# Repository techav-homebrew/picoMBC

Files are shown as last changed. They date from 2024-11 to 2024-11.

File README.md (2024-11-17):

# picoMBC

picoMBC is a generic Pi Pico expansion card for the Sanyo MBC-1000 computer. The primary goal is to add an SD card interface for mass storage, but with some available I/O for future or alternate use.

The MBC-1000 expansion interface is a buffered breakout of the Z80 I/O interface. It does not provide the upper 8 bits of the Z80 address bus or signals required for memory space addressing or DMA. To save I/O, picoMBC multiplexes the 8-bit data and address busses.

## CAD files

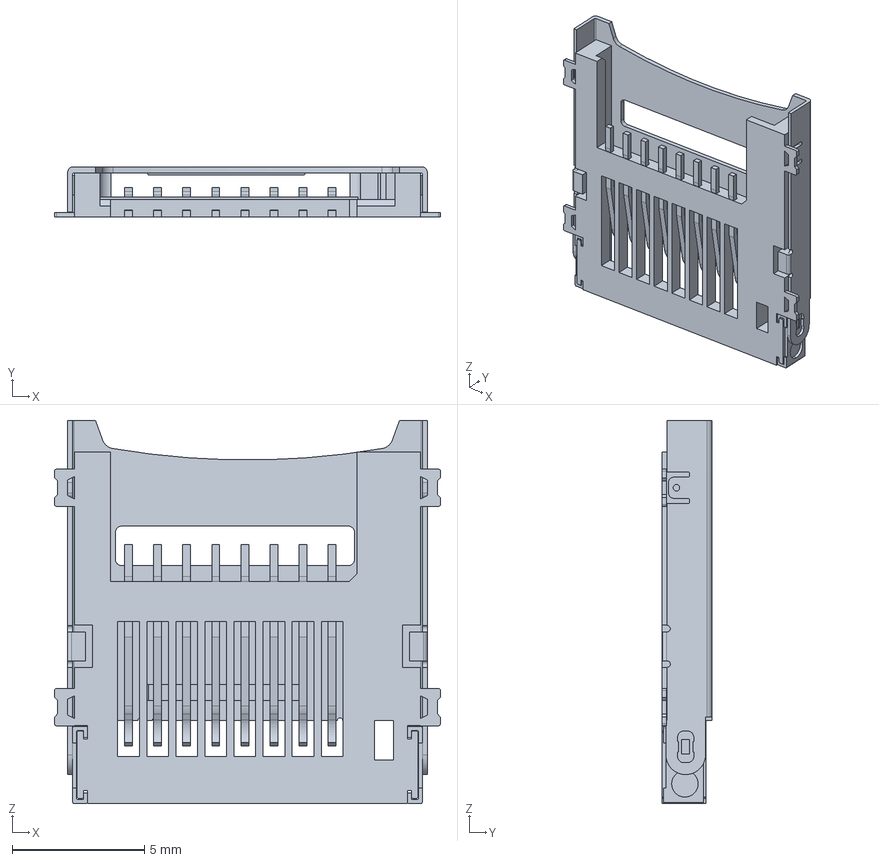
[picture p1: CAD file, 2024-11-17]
hardware/472192001.stp
14.6 x 1.90 x 14.5 mm

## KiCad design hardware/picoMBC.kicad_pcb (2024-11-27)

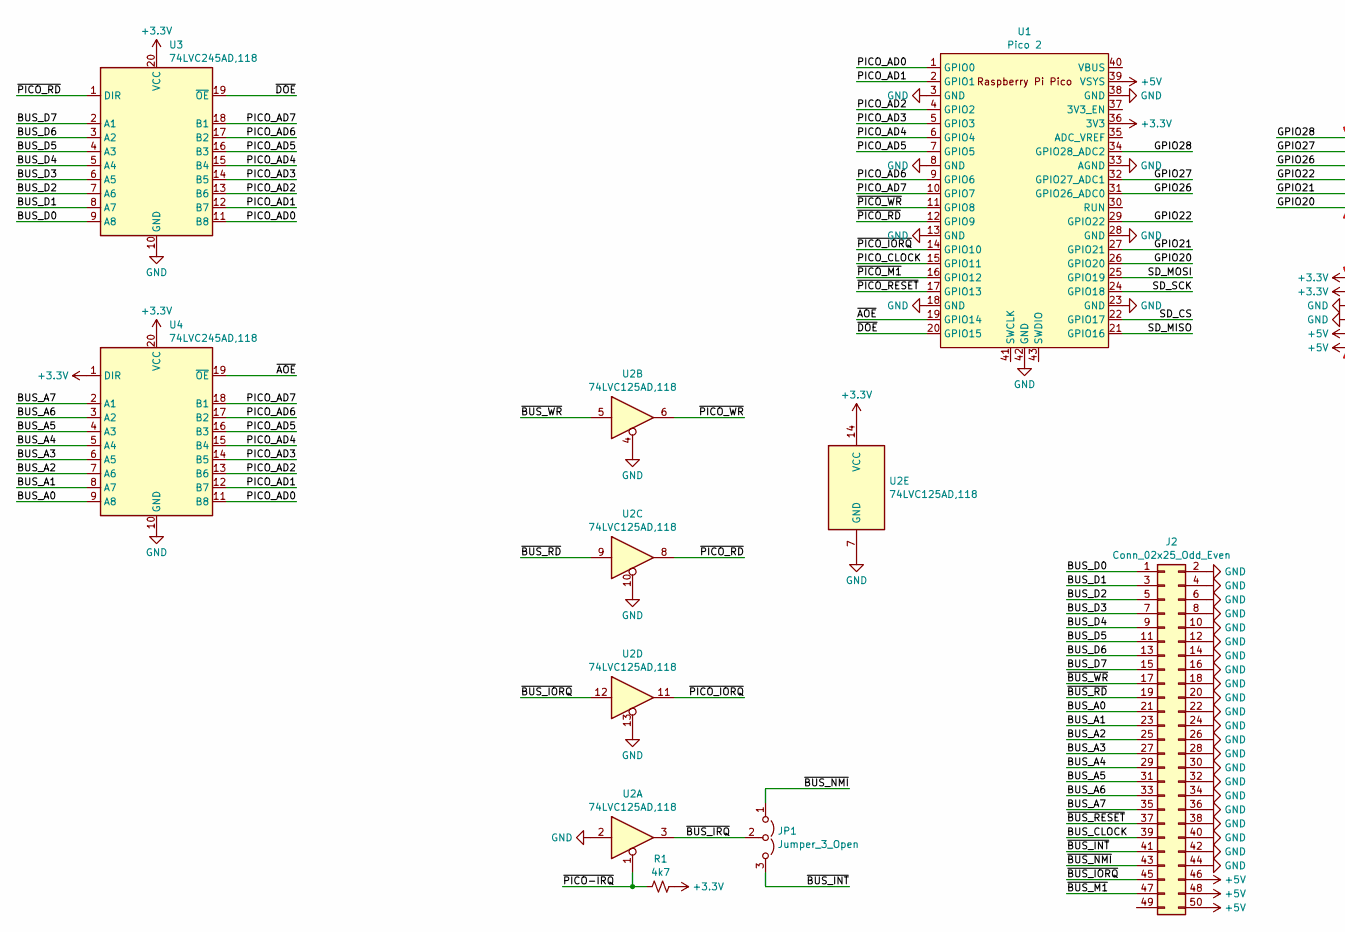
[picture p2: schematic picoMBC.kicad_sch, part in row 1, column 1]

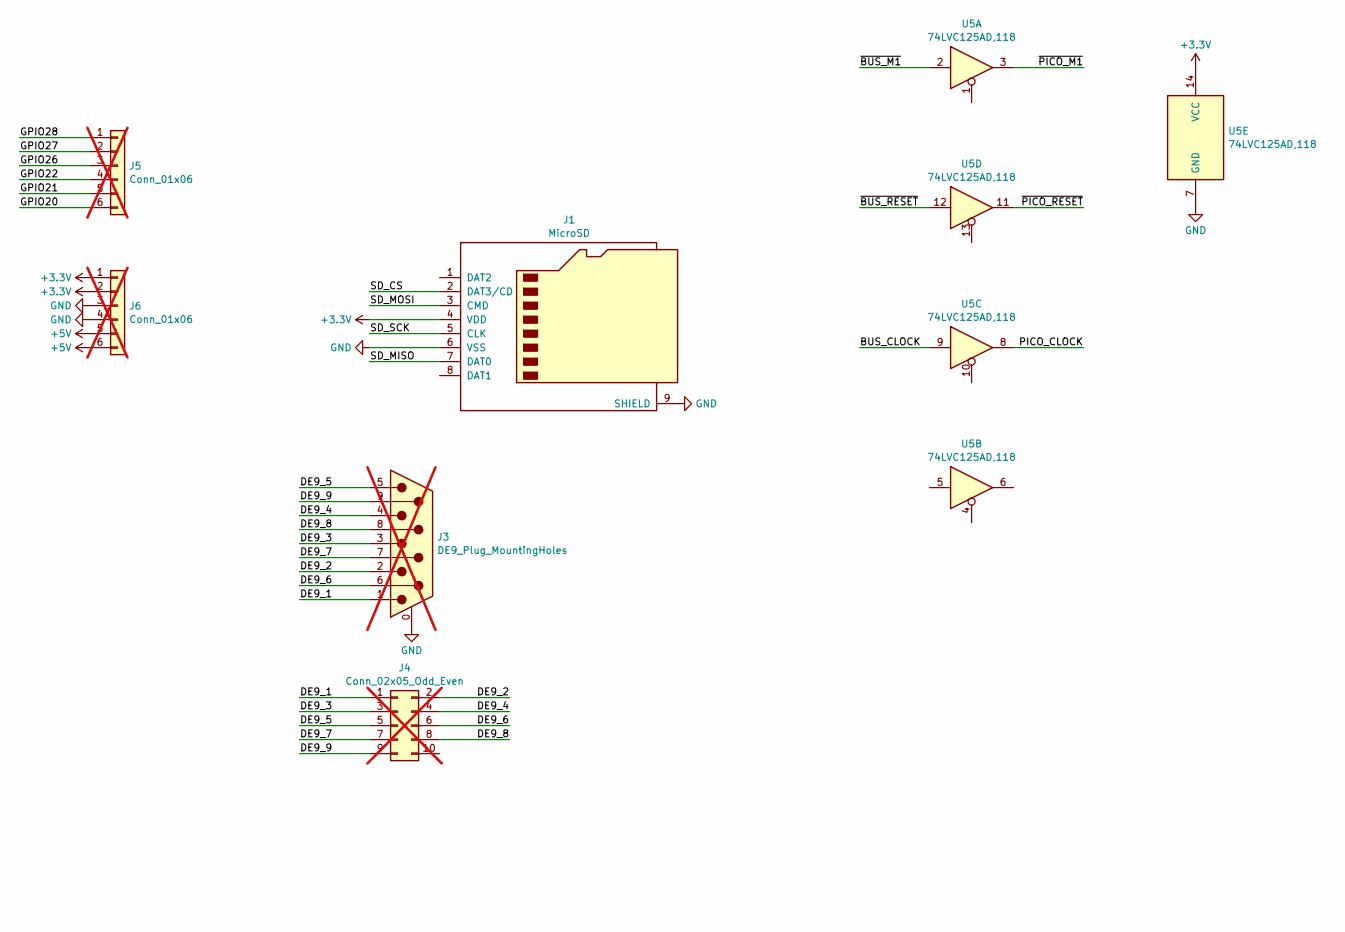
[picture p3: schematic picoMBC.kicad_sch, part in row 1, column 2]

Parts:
J1: MicroSD; microSD_HC_Molex_47219-2001
J2: Conn_02x25_Odd_Even; PinHeader_2x25_P2.54mm_Horizontal
J3: DE9_Plug_MountingHoles; DSUB-9_Male_Horizontal_P2.77x2.84mm_EdgePinOffset4.94mm_Hou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; not fitted
J4: Conn_02x05_Odd_Even; PinHeader_2x05_P2.54mm_Vertical; not fitted
J5, J6: Conn_01x06; PinHeader_1x06_P2.54mm_Vertical; not fitted
JP1: Jumper_3_Open; PinHeader_1x03_P2.54mm_Vertical
R1: 4k7; R_Axial_DIN0204_L3.6mm_D1.6mm_P7.62mm_Horizontal
U1: Pico 2; RPi_Pico_SMD_TH
U2, U5: 74LVC125AD,118; SOIC-14_3.9x8.7mm_P1.27mm; Mouser 771-74LVC125AD-T
U3, U4: 74LVC245AD,118; SOIC-20W_7.5x12.8mm_P1.27mm; Mouser 771-74LVC245AD-T

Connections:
+3.3V: J1.4 (VDD), J6.1, J6.2, R1.1, U1.36 (3V3), U2.14 (VCC), U3.20 (VCC), U4.1 (DIR), U4.20 (VCC), U5.14 (VCC)
+5V: J2.46, J2.48, J2.50, J6.5, J6.6, U1.39 (VSYS)
/BUS_A0: J2.21, U4.9 (A8)
/BUS_A1: J2.23, U4.8 (A7)
/BUS_A2: J2.25, U4.7 (A6)
/BUS_A3: J2.27, U4.6 (A5)
/BUS_A4: J2.29, U4.5 (A4)
/BUS_A5: J2.31, U4.4 (A3)
/BUS_A6: J2.33, U4.3 (A2)
/BUS_A7: J2.35, U4.2 (A1)
/BUS_CLOCK: J2.39, U5.9
/BUS_D0: J2.1, U3.9 (A8)
/BUS_D1: J2.3, U3.8 (A7)
/BUS_D2: J2.5, U3.7 (A6)
/BUS_D3: J2.7, U3.6 (A5)
/BUS_D4: J2.9, U3.5 (A4)
/BUS_D5: J2.11, U3.4 (A3)
/BUS_D6: J2.13, U3.3 (A2)
/BUS_D7: J2.15, U3.2 (A1)
/DE9_1: J3.1, J4.1
/DE9_2: J3.2, J4.2
/DE9_3: J3.3, J4.3
/DE9_4: J3.4, J4.4
/DE9_5: J3.5, J4.5
/DE9_6: J3.6, J4.6
/DE9_7: J3.7, J4.7
/DE9_8: J3.8, J4.8
/DE9_9: J3.9, J4.9
/GPIO20: J5.6, U1.26 (GPIO20)
/GPIO21: J5.5, U1.27 (GPIO21)
/GPIO22: J5.4, U1.29 (GPIO22)
/GPIO26: J5.3, U1.31 (GPIO26_ADC0)
/GPIO27: J5.2, U1.32 (GPIO27_ADC1)
/GPIO28: J5.1, U1.34 (GPIO28_ADC2)
/PICO_AD0: U1.1 (GPIO0), U3.11 (B8), U4.11 (B8)
/PICO_AD1: U1.2 (GPIO1), U3.12 (B7), U4.12 (B7)
/PICO_AD2: U1.4 (GPIO2), U3.13 (B6), U4.13 (B6)
/PICO_AD3: U1.5 (GPIO3), U3.14 (B5), U4.14 (B5)
/PICO_AD4: U1.6 (GPIO4), U3.15 (B4), U4.15 (B4)
/PICO_AD5: U1.7 (GPIO5), U3.16 (B3), U4.16 (B3)
/PICO_AD6: U1.9 (GPIO6), U3.17 (B2), U4.17 (B2)
/PICO_AD7: U1.10 (GPIO7), U3.18 (B1), U4.18 (B1)
/PICO_CLOCK: U1.15 (GPIO11), U5.8
/SD_CS: J1.2 (DAT3/CD), U1.22 (GPIO17)
/SD_MISO: J1.7 (DAT0), U1.21 (GPIO16)
/SD_MOSI: J1.3 (CMD), U1.25 (GPIO19)
/SD_SCK: J1.5 (CLK), U1.24 (GPIO18)
/~AOE: U1.19 (GPIO14), U4.19 (~OE)
/~BUS_INT: J2.41, JP1.3 (B)
/~BUS_IORQ: J2.45, U2.12
/~BUS_IRQ: JP1.2 (C), U2.3
/~BUS_M1: J2.47, U5.2
/~BUS_NMI: J2.43, JP1.1 (A)
/~BUS_RD: J2.19, U2.9
/~BUS_RESET: J2.37, U5.12
/~BUS_WR: J2.17, U2.5
/~DOE: U1.20 (GPIO15), U3.19 (~OE)
/~PICO-IRQ: R1.2, U2.1
/~PICO_IORQ: U1.14 (GPIO10), U2.11
/~PICO_M1: U1.16 (GPIO12), U5.3
/~PICO_RD: U1.12 (GPIO9), U2.8, U3.1 (DIR)
/~PICO_RESET: U1.17 (GPIO13), U5.11
/~PICO_WR: U1.11 (GPIO8), U2.6
GND: J1.6 (VSS), J1.9 (SHIELD), J2.2, J2.4, J2.6, J2.8, J2.10, J2.12, J2.14, J2.16, J2.18, J2.20, J2.22, J2.24, J2.26, J2.28, J2.30, J2.32, J2.34, J2.36, J2.38, J2.40, J2.42, J2.44, J3.0 (PAD), J6.3, J6.4, U1.3 (GND), U1.8 (GND), U1.13 (GND), U1.18 (GND), U1.23 (GND), U1.28 (GND), U1.33 (AGND), U1.38 (GND), U1.42 (GND), U2.2, U2.4, U2.7 (GND), U2.10, U2.13, U3.10 (GND), U4.10 (GND), U5.7 (GND)

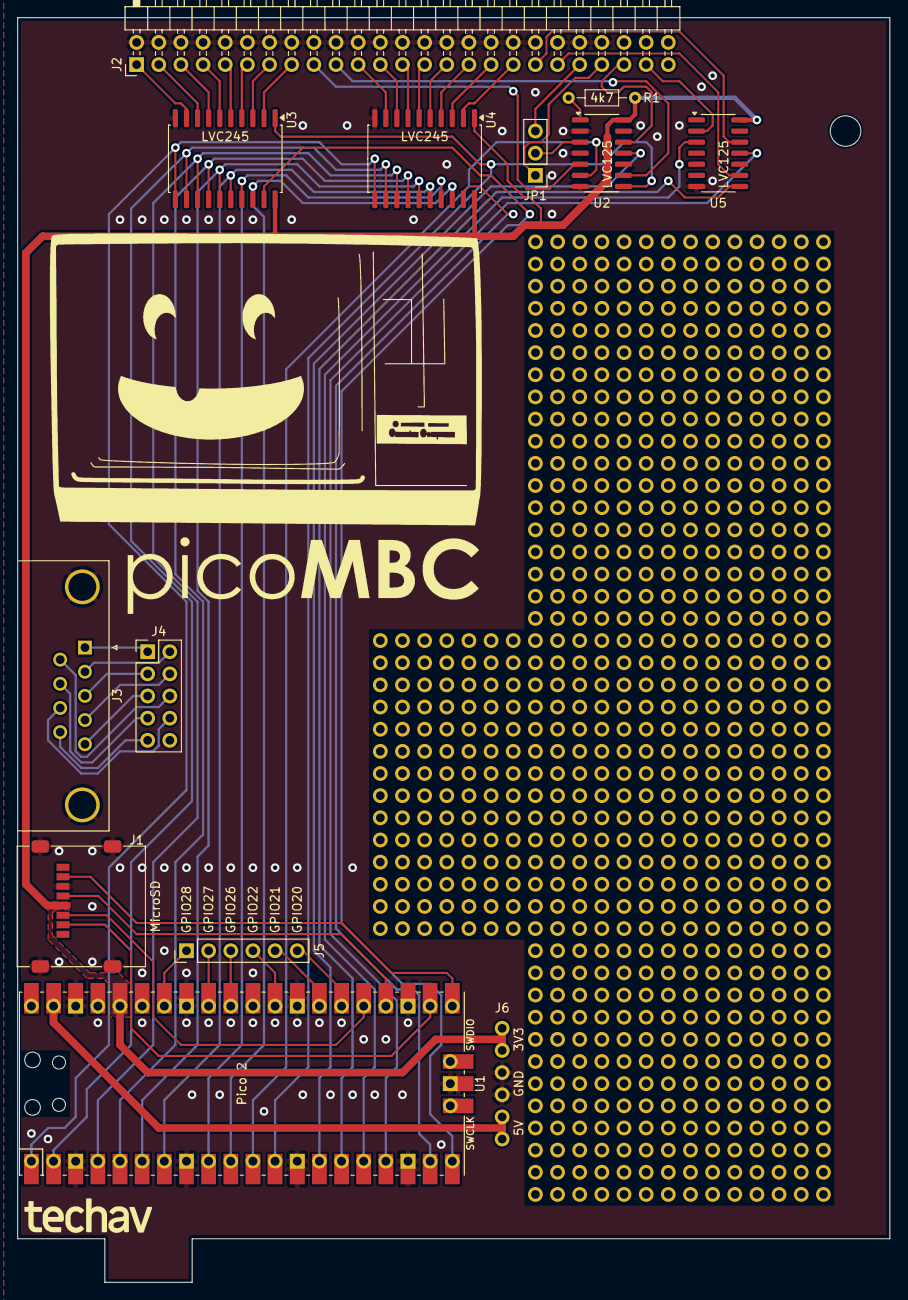
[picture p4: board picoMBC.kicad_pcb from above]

Board: 2 copper layers, 100.0 x 145.0 mm, 13 parts (0 on the bottom side), 64 nets.

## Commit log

2024-11-17 Multiplex pico bus
    - add buffers to multiplex Pico bus to free up some I/O for future use
    [picoMBC.kicad_pcb, picoMBC.kicad_sch]
2024-11-27 add power header & plot gerbers
    [picoMBC-B_Cu.gbl, picoMBC-B_Mask.gbs, picoMBC-B_Paste.gbp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]
